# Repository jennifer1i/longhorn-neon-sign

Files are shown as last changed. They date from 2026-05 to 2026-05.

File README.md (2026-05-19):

# Neon Sign Interface Board RevB - Jennifer Li

## Board Description
- Compact 2-layer PCB for PWM-controlled LED driving using nMOSFET switching and onboard 12V->5V buck regulation. Revision of neon sign project from Summer 2025 with stronger consideration for manufacturability, testability, thermal management, compact routing, and aesthetics. 
## Features
- 12V input power architecture
- 12V->5V integrated buck converter
- Multi-channel nMOSFET LED control
- Arduino-Nano based LED toggling and dimming
- Optimized for compact and clean routing
- SMT/SMD and THT assembly
- Testpoints for GND, 12V, 5V, and PWM
- Indicator LEDs with blank silkscreen for post-production debugging

## Design Notes
- The PCB was designed to be rectangular, optimizing balanced LED power distribution and component placement. Testpoints and button switches were placed along the sides for easier access in the debugging process. 
- For this design, I chose to have two LED output terminals after evaluating the maximum load requirement of the targeted LED strips. The strips I chose draw up to 5A, and thus my output circuits were designed to handle up to roughly 2.5A.
- In addition, these two terminals were placed on opposite ends of the PCB's length to simplify high-current routing, reduce congestion, and distribute power evenly across the final neon sign product without unecessary harnessing cross-over. To accomodate this placement, I used a 12V pour on the top layer in an area with minimal top-layer GND pads and minimal top-layer routing. Thus, I could provide a clean low-impedance power distribution between the input stage and the LED ouptut terminal on the opposite end of the board. 
  
## PCB Specificaitions
- Layers: 2
- PCB Thickness: 1.6 mm
- Assembly: SMT/SMD and THT
- Designed in KiCad

## Future Improvements
- Switch to addressable LED strips for firmware-controlled animation and color effects
- Transition to a fully integrated MCU system (ESP32) directly mounted on the PCB
- Use lower-profile connectors like Molex Nanofits instead of screw terminals
- Rework the user input interface, using more ergonomic control interfaces like potentiometers, rotary encoders, or low-profile switches
- Add additional protection circuitry including input fuses, TVS diodes, reverse-polarity protection, and overvoltage and undervoltage protection
- Implement per-channel current sensing and thermal monitoring
- Enable PG pin for buck converter and add output sensing

## Top Layer

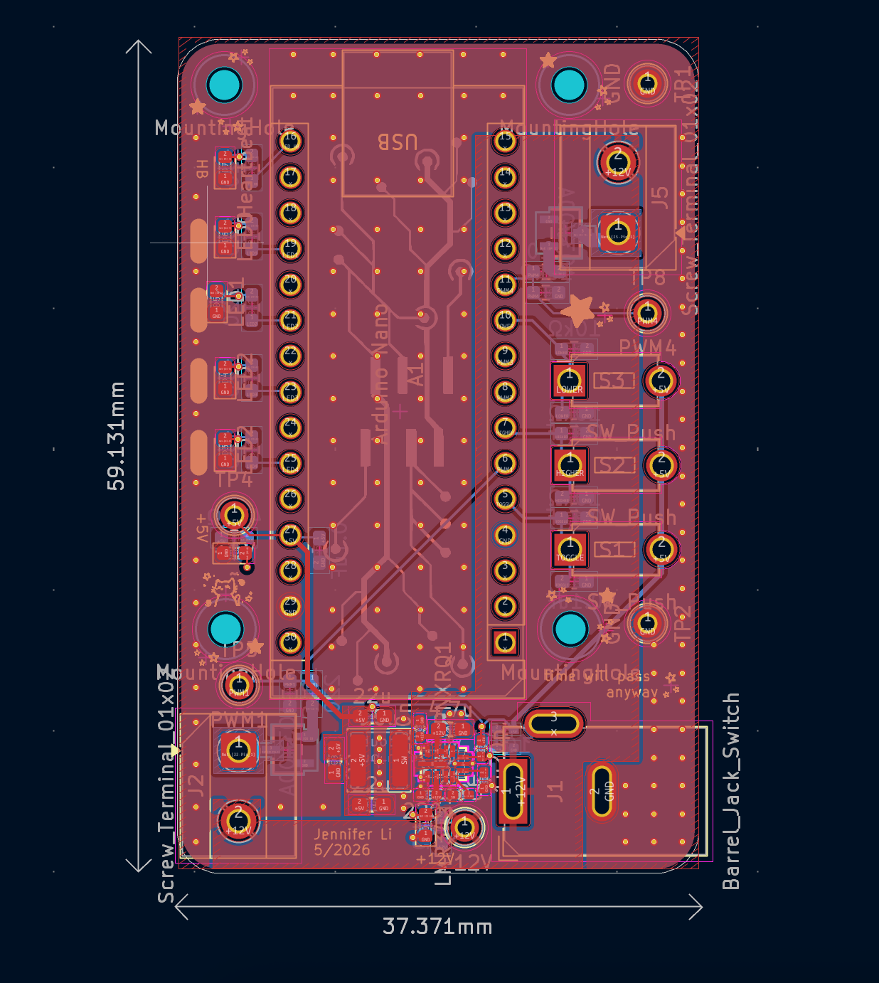
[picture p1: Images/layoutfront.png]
Top Layer


## Back Layer

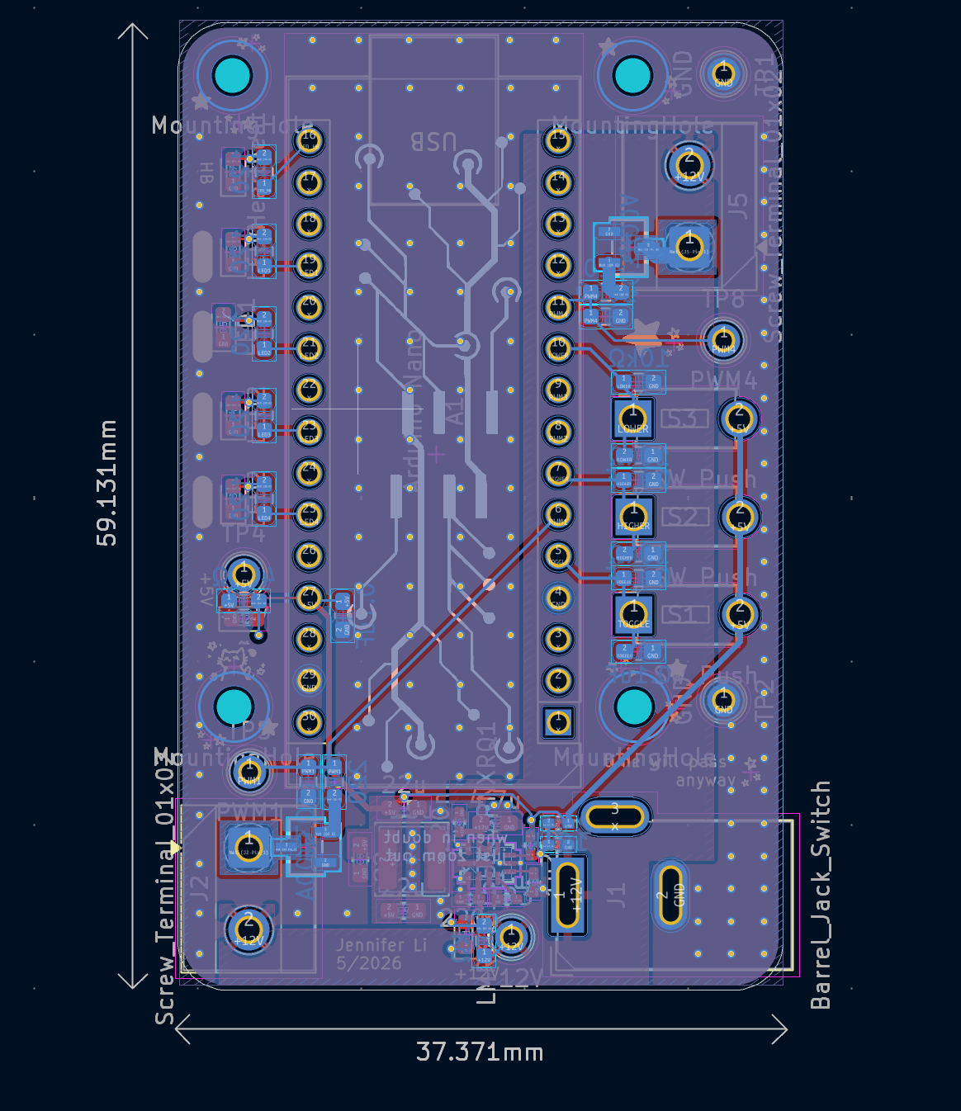
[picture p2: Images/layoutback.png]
Back Layer


## 3D Render
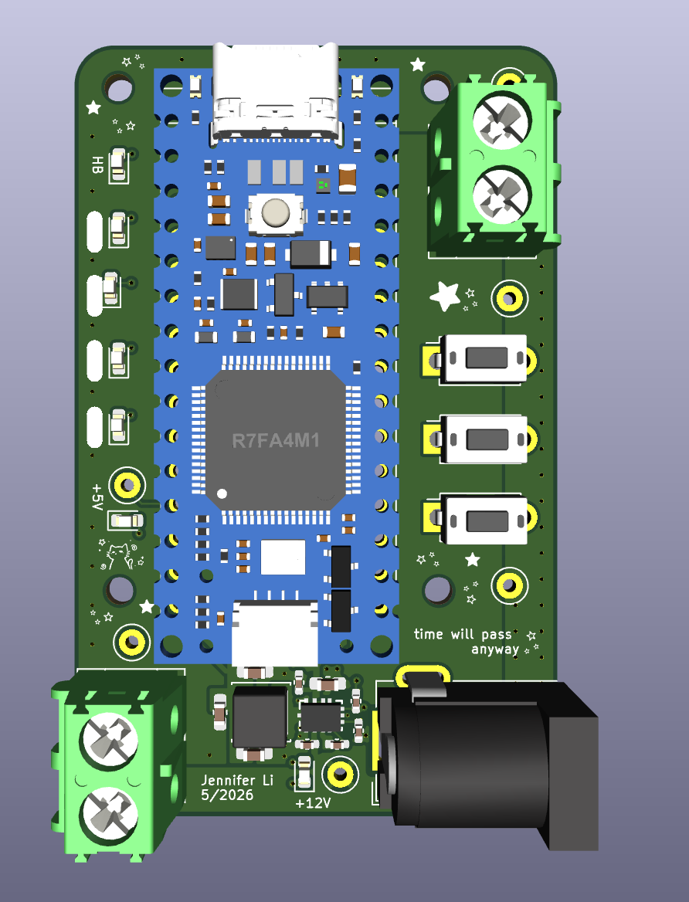
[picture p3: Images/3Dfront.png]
Front View

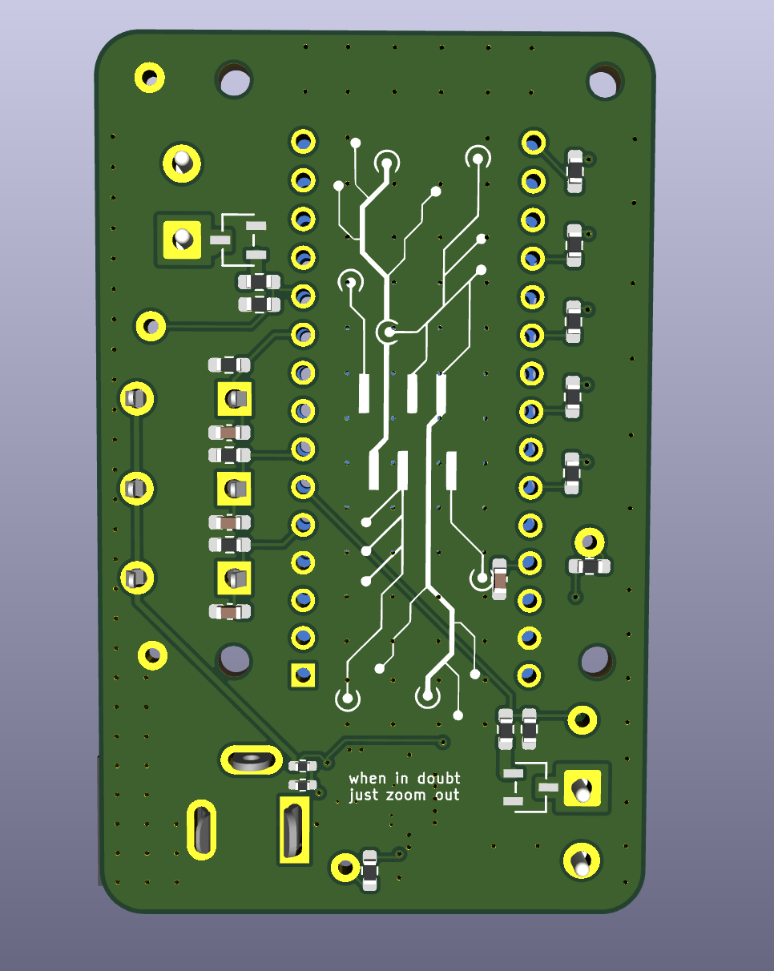
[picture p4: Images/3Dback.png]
Back View


## Root Schematic

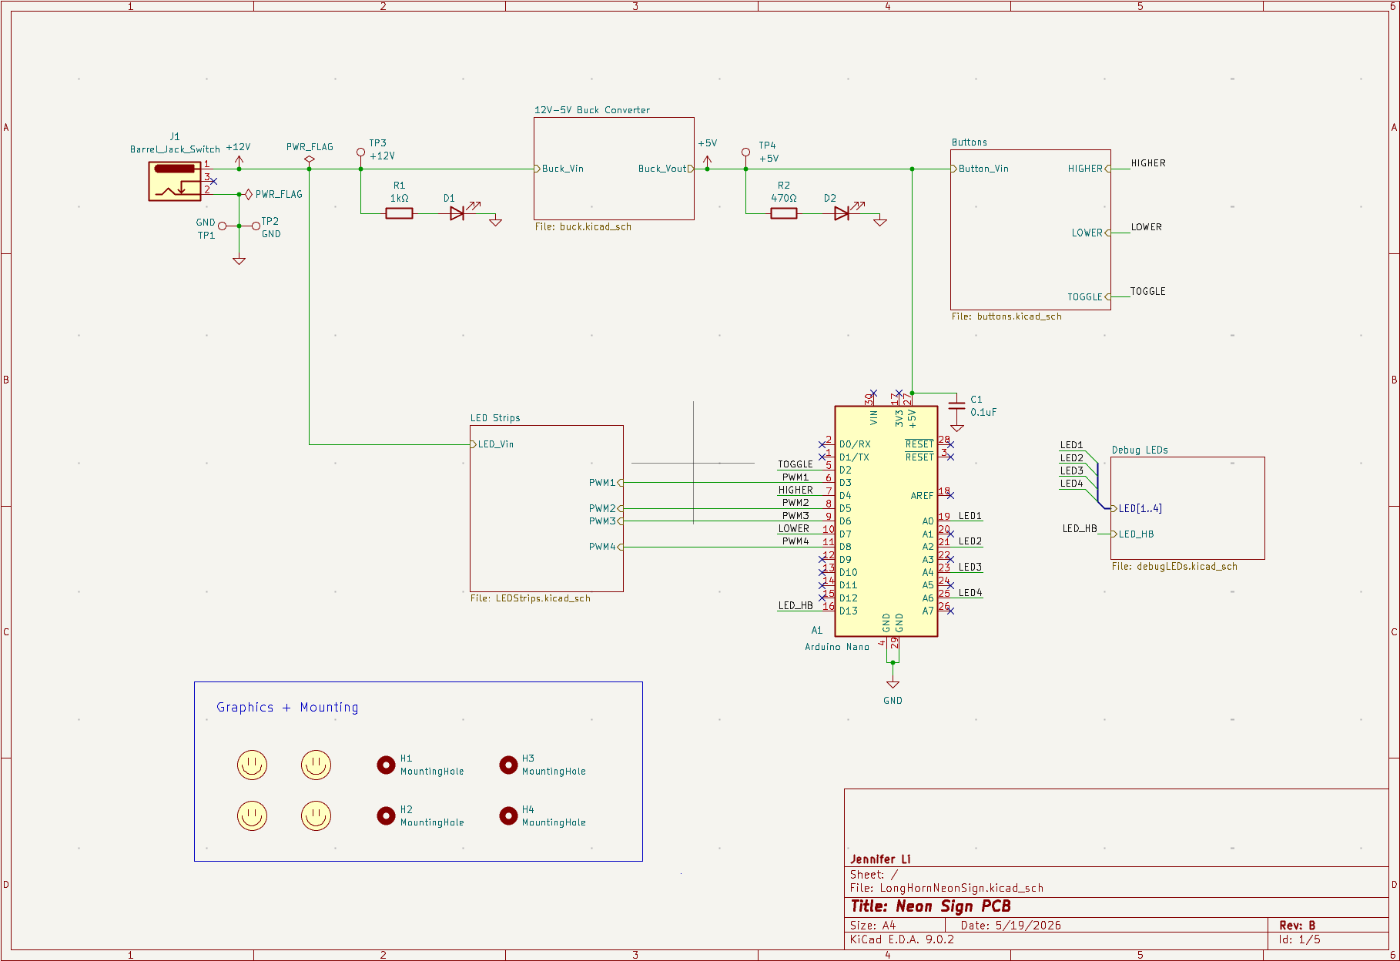
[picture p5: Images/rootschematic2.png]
Root Schematic


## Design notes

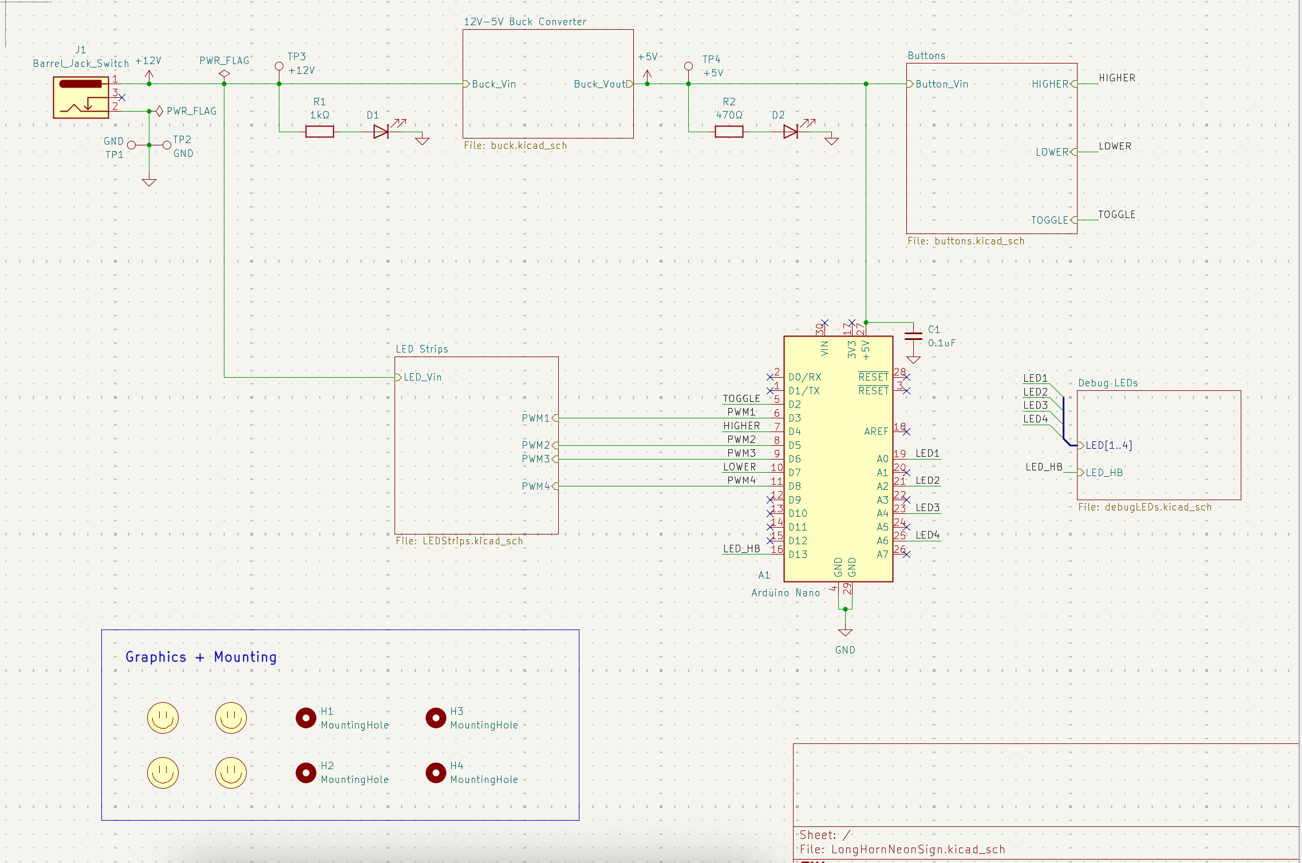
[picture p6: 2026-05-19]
Images/rootschematic.png

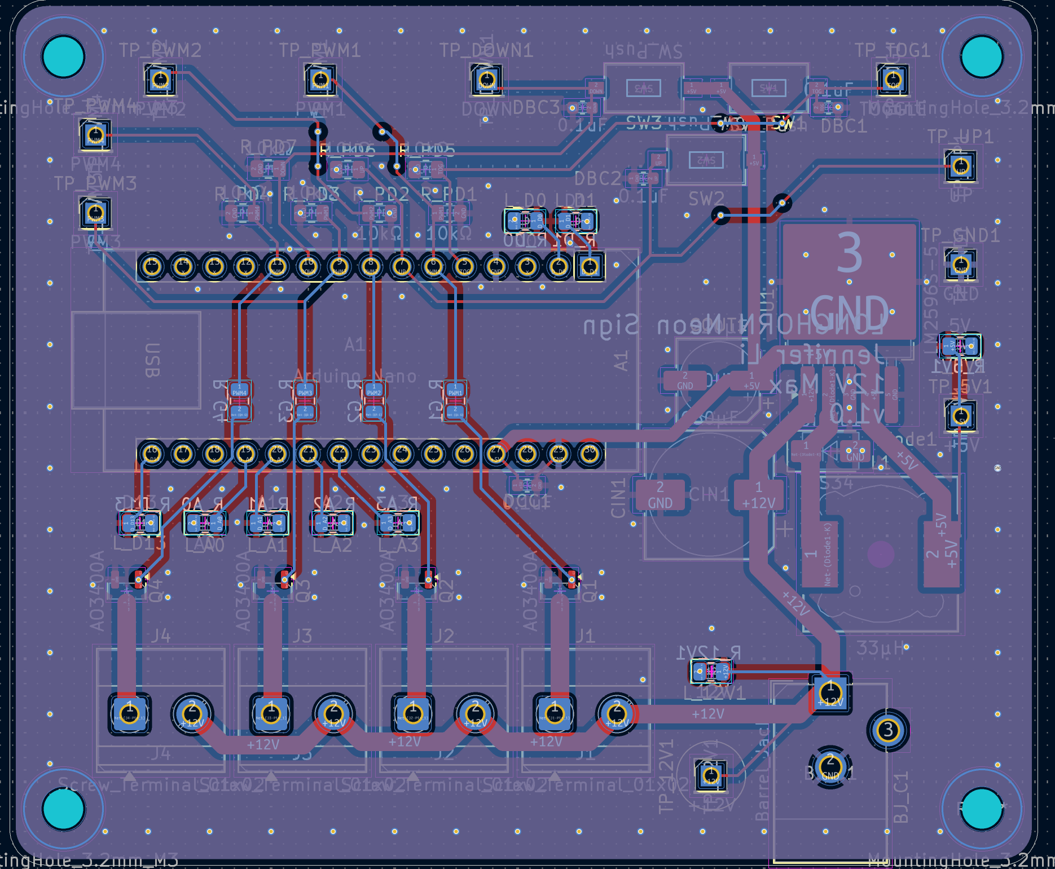
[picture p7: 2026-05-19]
Images/NeonSign PCB Pic 2.png

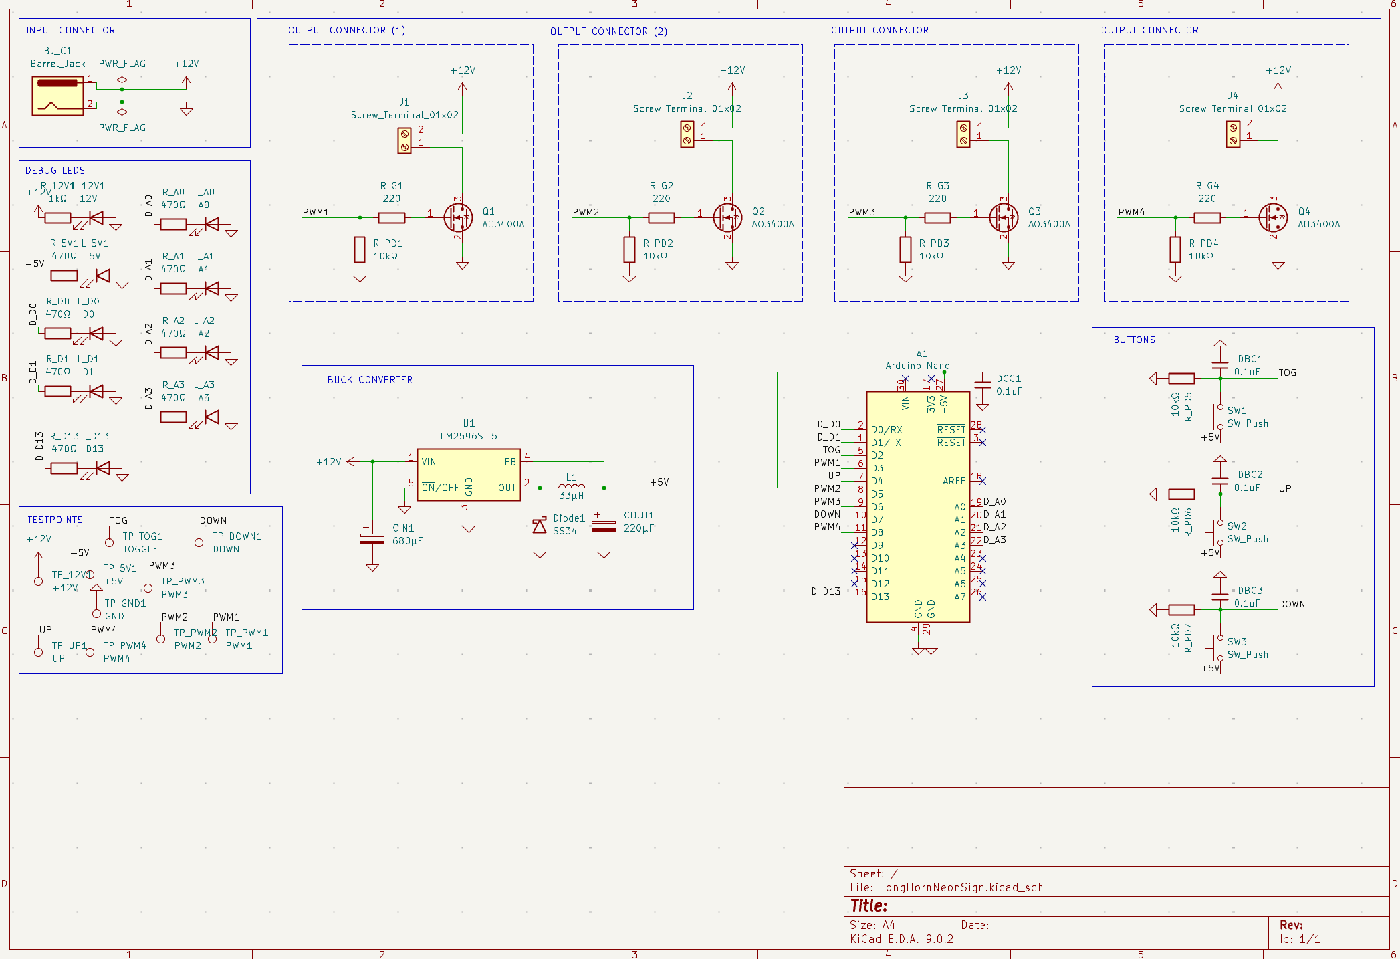
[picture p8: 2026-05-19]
Images/NeonSign Sch Pic.png

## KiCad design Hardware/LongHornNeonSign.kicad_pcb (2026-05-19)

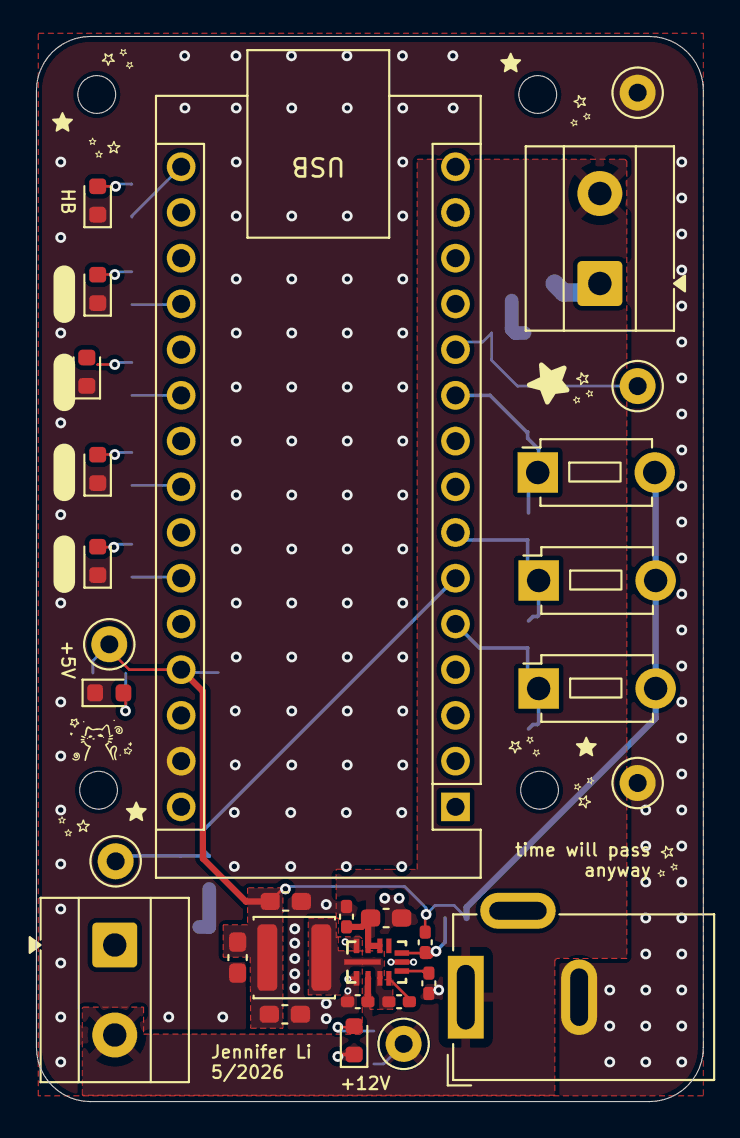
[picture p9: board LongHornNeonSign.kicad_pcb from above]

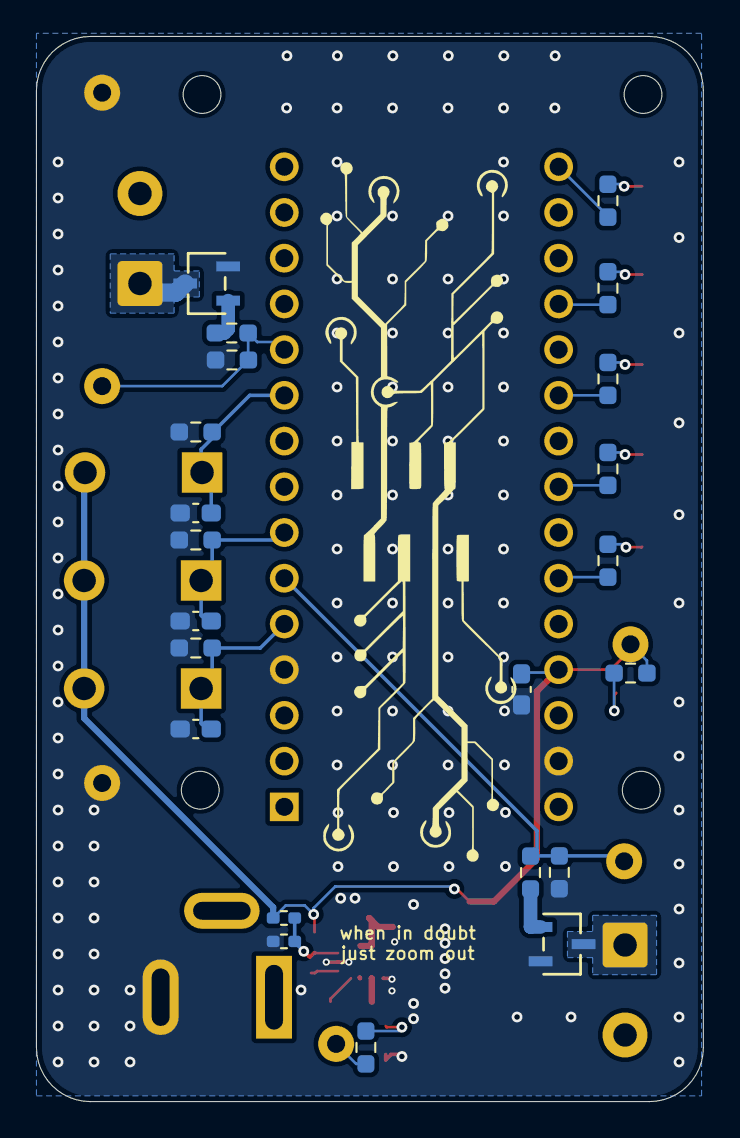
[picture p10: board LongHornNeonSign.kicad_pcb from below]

Board: 2 copper layers, 37.0 x 59.2 mm, 57 parts (22 on the bottom side), 28 nets.

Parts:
A1: Arduino Nano; Arduino_Nano
C1, C11, C12, C13: 0.1uF; C_0603_1608Metric_Pad1.08x0.95mm_HandSolder
C2: 4.7u; C_0603_1608Metric_Pad1.08x0.95mm_HandSolder
C3, C4: 220n; C_0402_1005Metric_Pad0.74x0.62mm_HandSolder
C5: 1u; C_0402_1005Metric_Pad0.74x0.62mm_HandSolder
C6: .1u; C_0402_1005Metric_Pad0.74x0.62mm_HandSolder
C7: 20p; C_0402_1005Metric_Pad0.74x0.62mm_HandSolder
C8, C9, C10: 22u; C_0603_1608Metric_Pad1.08x0.95mm_HandSolder
D1, D2: LED_0603_1608Metric
D3, D4: LED2; LED_0603_1608Metric
D5: LED1; LED_0603_1608Metric
D6: LED0; LED_0603_1608Metric
D7: Heartbeat; LED_0603_1608Metric
H1, H2, H3, H4: MountingHole; MountingHole_2.1mm
J1: Barrel_Jack_Switch; BarrelJack_GCT_DCJ200-10-A_Horizontal
J2, J5: Screw_Terminal_01x02; TerminalBlock_MetzConnect_Type055_RT01502HDWU_1x02_P5.00mm_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
L1: 15u; L_APV_ANR4030
Q1, Q4: AO3400A; SOT-23-3L_AOS
R1: 1kΩ; R_0603_1608Metric_Pad0.98x0.95mm_HandSolder
R2: 470Ω; R_0603_1608Metric_Pad0.98x0.95mm_HandSolder
R3: 100k; R_0402_1005Metric_Pad0.72x0.64mm_HandSolder
R4: 24.9k; R_0402_1005Metric_Pad0.72x0.64mm_HandSolder
R5, R10, R13, R14, R15: 10kΩ; R_0603_1608Metric_Pad0.98x0.95mm_HandSolder
R7, R12: 220; R_0603_1608Metric_Pad0.98x0.95mm_HandSolder
R16, R17, R18, R19, R20: 120; R_0603_1608Metric_Pad0.98x0.95mm_HandSolder
S1, S2, S3: SW_Push; SW_PUSH_1P1T_6x3.5mm_H4.3_APEM_MJTP1243
TP1, TP2: GND; TestPoint_Keystone_5000-5004_Miniature
TP3: +12V; TestPoint_Keystone_5000-5004_Miniature
TP4: +5V; TestPoint_Keystone_5000-5004_Miniature
TP5: PWM1; TestPoint_Keystone_5000-5004_Miniature
TP8: PWM4; TestPoint_Keystone_5000-5004_Miniature
U1: LMR34215FSC5RNXRQ1; RNX12_TEX

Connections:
+5V: A1.27 (+5V), C1.1, C7.2, C8.2, C9.2, C10.2, L1.2, R2.1, R3.1, S1.2, S2.2, S3.2, TP4.1
+12V: C2.2, C3.2, C4.2, J1.1, J2.2, J5.2, R1.1, TP3.1, U1.2 (VIN), U1.9 (EN), U1.10 (VIN)
/12V-5V Buck Converter/SW: C6.2, L1.1, U1.3 (NC), U1.12 (SW)
/Debug LEDs/LED1: A1.19 (A0), R19.1
/Debug LEDs/LED2: A1.21 (A2), R18.1
/Debug LEDs/LED3: A1.23 (A4), R17.1
/Debug LEDs/LED4: A1.25 (A6), R16.1
/HIGHER: A1.7 (D4), C12.2, R14.1, S2.1
/LED_HB: A1.16 (D13), R20.1
/LOWER: A1.10 (D7), C13.2, R15.1, S3.1
/PWM1: A1.6 (D3), R5.1, R7.1, TP5.1
/PWM4: A1.11 (D8), R10.1, R12.1, TP8.1
/TOGGLE: A1.5 (D2), C11.2, R13.1, S1.1
GND: A1.4 (GND), A1.29 (GND), C1.2, C2.1, C3.1, C4.1, C5.1, C8.1, C9.1, C10.1, C11.1, C12.1, C13.1, D1.1 (K), D2.1 (K), D3.1 (K), D4.1 (K), D5.1 (K), D6.1 (K), D7.1 (K), J1.2, Q1.2 (S), Q4.2 (S), R4.2, R5.2, R10.2, R13.2, R14.2, R15.2, TP1.1, TP2.1, U1.1 (PGND), U1.6 (AGND), U1.11 (PGND)
unnamed: D1.2 (A), R1.2
unnamed: D2.2 (A), R2.2
unnamed: D3.2 (A), R16.2
unnamed: D4.2 (A), R17.2
unnamed: D5.2 (A), R18.2
unnamed: D6.2 (A), R19.2
unnamed: D7.2 (A), R20.2
unnamed: J2.1, Q1.3 (D)
unnamed: J5.1, Q4.3 (D)
unnamed: Q1.1 (G), R7.2
unnamed: Q4.1 (G), R12.2
unnamed: C6.1, U1.4 (BOOT)
unnamed: C7.1, R3.2, R4.1, U1.7 (FB)
unnamed: C5.2, U1.5 (VCC)

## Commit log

2025-07-08 Fixed schematic
    [LongHornNeonSign.kicad_sch]
2025-07-12 update sch
    [LongHornNeonSign.kicad_sch]
2025-07-12 Added testpoint example
    [LongHornNeonSign.kicad_pcb, LongHornNeonSign.kicad_sch]
2025-07-13 sch done
    [LongHornNeonSign.kicad_sch]
2025-07-21 updated pcb
    [LongHornNeonSign.kicad_pcb]
2025-07-21 update pcb
    [LongHornNeonSign.kicad_pcb]
2026-05-12 May 12 2026 run it back
    [LongHornNeonSign.kicad_pcb, LongHornNeonSign.kicad_sch]
2026-05-19 done layout 5/18/2026
    [LEDStrips.kicad_sch, LongHornNeonSign.kicad_pcb, LongHornNeonSign.kicad_sch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]
2026-05-19 clean up
    [LongHornNeonSign.kicad_pcb, LongHornNeonSign.kicad_sch]
2026-05-19 finalize PCB, added images and silkscreen text and 3D models
    [LongHornNeonSign.kicad_pcb]
2026-05-19 push RevB's README and edit schematic specs
    [LongHornNeonSign.kicad_sch]
